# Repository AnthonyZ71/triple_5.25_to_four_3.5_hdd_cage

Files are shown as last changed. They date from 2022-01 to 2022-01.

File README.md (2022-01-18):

# Overview
OpenSCAD project to create a cage that fits in 3 5.25" drive bays and holds 4 3.5" hard drives using rails.

Optionally supports a fan shroud to provide additional airflow to the drives.

You need to print:

- 1 cage-cage.stl
- 8 cage-rail.stl
- [optional] 4 cage-fan_mounting_pin.stl
- [optional] 1 of the cage-fan_shroud stl files.

Note:  Monitor the print closely when printing the fan mounting pins.
They are very small and can detach from the bed fairly easily.
If you continue to have problems, perhaps print the pins on a raft.

Pictures are of the cage-fan_shroud_web.stl

Note that the cage has a cylinder channel cut out at the top and bottom on one side.
The channel is for routing the power cable of the fan to the back of the case.
It should be on the left side of the cage when it is inserted into the case.

- Code: [Github Repository](https://github.com/AnthonyZ71/triple_5.25_to_four_3.5_hdd_cage)
- STLs:
  - [Prusa Printers](https://www.prusaprinters.org/prints/120546-triple-525-bay-to-four-35-hard-drives-cage)

# Printing Notes
All parts except the rail are designed to be printed without supports.

I print all parts except the rail with typical settings for the material in which they are being printed.
- 5% infill is sufficient

For the rail:
- Plater -> 5% infill
- Plater -> Support on build plate only
- Print Settings -> Layers and perimeters -> Vertical shells -> Perimeters: 3
- Print Settings -> Layers and perimeters -> Quality -> Detect bridging perimeters: true
- Print Settings -> Support material -> Support material -> Overhang threshold -> 40

This should cause very little support to be generated by the pegs for the hard drives and the clip for latching into the cage.
The rest of the rail should not require support.

Note that the number of perimeters is increased from 2 to 3 to ensure that the pin of the rail is solid.
Check the result of slicing the rail, you only need enough perimeters to ensure a solid pin.

## Optional test print
The cage-test.stl doesn't need to be printed at all unless you want to test the tolerances with your printer before committing to a full print.
The components of the test print are all oriented as they would be printed individually, and allows validation of size / spacing of the print before committing the time to print all of the components.
The parts of the test print are:
- A single full channel and rail to allow validation that the rail slides easily and locks into the cage.
- A single fan shroud mounting pin to ensure that it will connect the front of the case to the fan shroud
- A slice of the cage to validate that it will slide into the bay openings for your computer
- A small portion of the fan shroud to ensure that the mounting pin will connect the shroud to the front of the cage.  (note that it is ok that the pin spins in the mounting holes.  Once all four pins lock the shroud to the full cage, it prevents movement.)

# My Equipment
- Prusa MK3
- PrusaSlicer-2.3.3

# References

Several other projects aided in the creation on this HDD cage.

## Modified Parametric Pin Connectors
This project makes use of [Modified Parametric Pin Connectors](https://www.thingiverse.com/thing:3218332) by [acwest](https://www.thingiverse.com/acwest/designs) on thingiverse.  After testing other fan mounting mechanisms, I liked using this pin and socket mechanism, primarily because even if I end up accidentally breaking a pin, printing out a new part is minutes, not hours.

## Customizable Fan Grill Covers
This project makes use of [Customizable Fan Grill Covers](https://www.thingiverse.com/thing:4837562) by [OutwardB](https://www.thingiverse.com/OutwardB) on thingiverse.

Several preset grills are provided using these settings:

all:
- Frame -> fan preset: 120mm
- Frame -> frame option: full
- Frame -> screw hole chamfer: bottom
- Frame -> min border size in millimeter: 5
- Pattern -> line size in millimeter: 1.6
- Advanced | Frame Setting -> rounded corners: no

crosshair
- Pattern -> grill pattern: crosshair
- Pattern -> line space in millimeter:  19.0

crosshex
- Pattern -> grill pattern: crosshex
- Pattern -> line space in millimeter:  8.0

grid:
- Pattern -> line space in millimeter:  8.0

teardrop:
- Pattern -> line space in millimeter:  8.0
- Pattern -> grill pattern rotation: 180

web:
- Pattern -> grill pattern: web
- Pattern -> line space in millimeter:  19.0

none:
- Frame -> screw hole chamfer: no

To create a custom grill, you can use any STL file that fits the grill pattern with the expectation that the front of the grill is what is facing down on the printer bed and that the center of the grill is at the origin [0, 0, 0] when the STL is loaded into OpenSCAD.
Use the settings describe above if using OutwardB's custom fan grill cover generator, and then make the desired changes, render, and export the STL as fan_cover_custom.stl
Then in OpenSCAD, select "fan_shroud" as the part, grill style of custom.
You will then see the customized fan shroud.
Render it and export the STL.

# Final Note
The current pictures are of an early iteration that used hinges for the fan shroud/cage instead of the pins.
The fan shroud was painted black to match the case.
All of the testing of the design worked fine until it was put into the case for actual use.
The fan shroud does not open far enough to access the drives.
With the fan shroud attached, the front of the case cannot be removed.
See the makes for pictures of the new design and I will update my photos when I reprint the case in the future.
The latest iteration is much better than the photos.

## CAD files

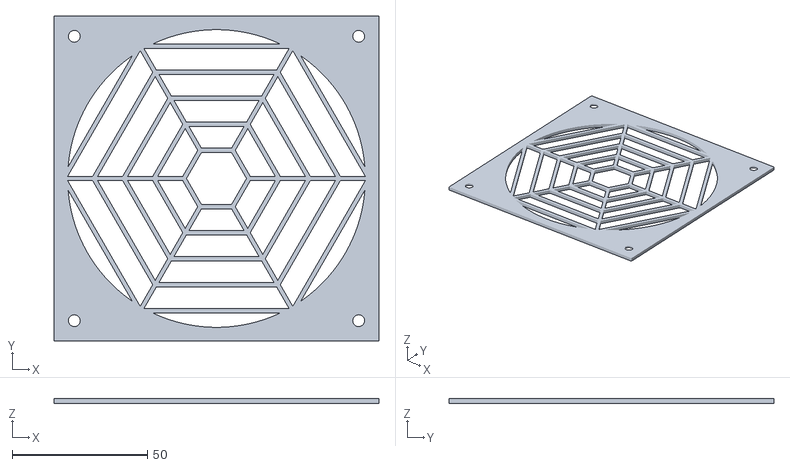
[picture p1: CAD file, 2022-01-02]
fan_cover_crosshex.stl
120.0 x 120.0 x 1.80

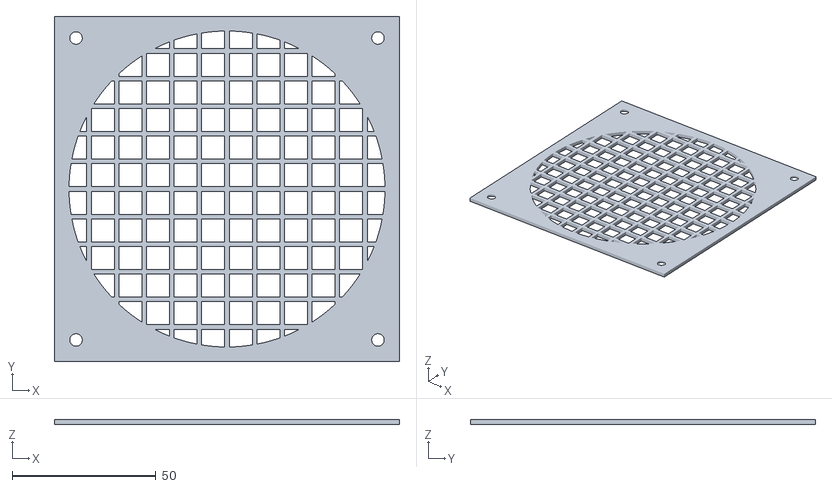
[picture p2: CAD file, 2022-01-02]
fan_cover_grid.stl
120.0 x 120.0 x 1.80

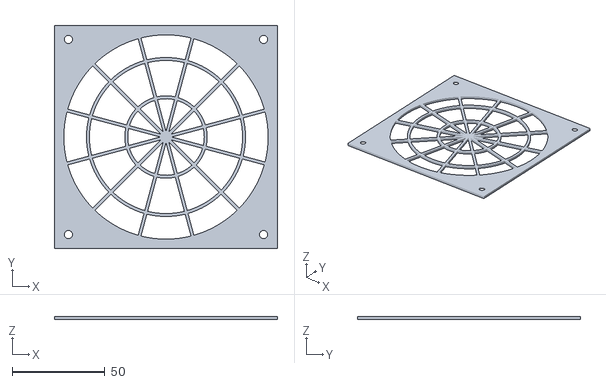
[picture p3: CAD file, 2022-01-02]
fan_cover_crosshair.stl
120.0 x 120.0 x 1.80

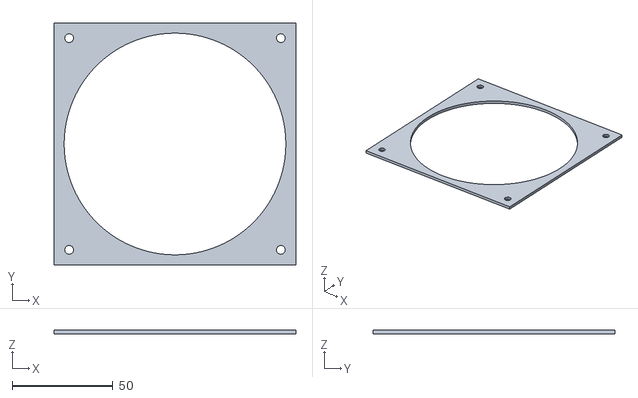
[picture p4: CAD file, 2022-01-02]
fan_cover_none.stl
120.0 x 120.0 x 1.80

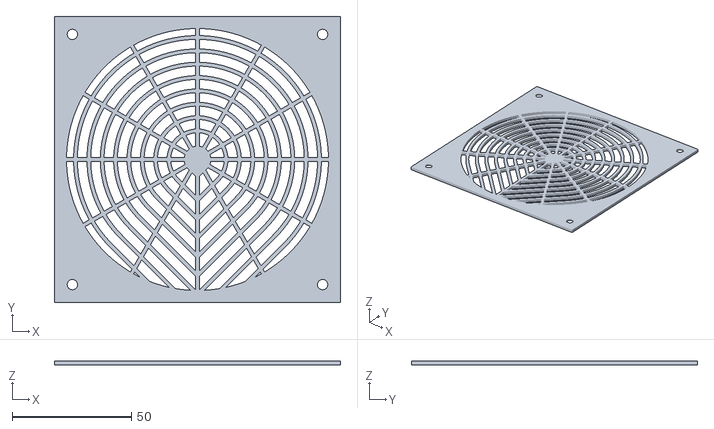
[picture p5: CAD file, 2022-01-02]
fan_cover_teardrop.stl
120.0 x 120.0 x 1.80

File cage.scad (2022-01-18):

use <snap-pins.scad>;

PART = "test"; // ["cage", "rail", "fan_shroud", "fan_mounting_pin", "test"]
// Select the grill style for the fan shroud.  Use custom and replace the fan_cover_custom.stl with your custom grill (see README.md for more details.)  Select none for an empty hole with an externally mounted grill cover.
grill_style = "fan_cover_web.stl"; // [fan_cover_crosshair.stl:crosshair,fan_cover_crosshex.stl:crosshex,fan_cover_grid.stl:grid,fan_cover_teardrop.stl:teardrop,fan_cover_web.stl:web,fan_cover_custom.stl:custom,fan_cover_none.stl:none]

include_fan_mount = true;

fan_grill_cover_height = 2;
shroud_h = 26;
shroud_inset = 11;

// How much tolerance to add to the prints.  This primarily impacts the rail channels, but also has some other impacts such as the pins on the rail that plug into the hard drive.
tolerance = .2;

bay_h = 41.3 + tolerance;
bay_w = 146.1 + tolerance;

drive_h = 29 + tolerance; // 41 + tolerance;
drive_w = 146 + tolerance;
drive_l = 165 + tolerance;

// See https://toshiba.semicon-storage.com/us/storage/support/faq/storage-holes.html
hdd_a1  =  26.10 + 0;
hdd_a2  = 147.00 + 0;
hdd_a3  = 101.60 + 0;
hdd_a4  =  95.25 + 0;
hdd_a5  =   3.18 + 0;
hdd_a6  =  44.45 + 0;
hdd_a7  =  41.28 + 0;
hdd_a8  =  28.50 + 0;
hdd_a9  = 101.60 + 0;
hdd_a10 =   6.35 + 0;
hdd_a13 =  76.20 + 0;

// See SFF-8551
cd_a1  =  41.53 + 0;
cd_a2  =  42.30 + 0;
cd_a3  = 148.00 + 0;
cd_a4  = 202.80 + 0;
cd_a5  = 146.05 + 0;
cd_a6  = 139.70 + 0;
cd_a7  =   3.18 + 0;
cd_a8  =  79.25 + 0;
cd_a9  =  47.40 + 0;
cd_a10 =  47.40 + 0;
cd_a11 =  79.25 + 0;
cd_a13 =  10.00 + 0;
cd_a14 =  21.84 + 0;
cd_a16 =   6.50 + 0;
cd_a17 =   5.00 + 0;

hdd_h = hdd_a1 + tolerance;
hdd_w = hdd_a3 + tolerance;
hdd_l = hdd_a2 + tolerance;

cage_h = 125.75 + 0;
cage_w = 145 + 0; // 146;
cage_l = hdd_a2 - hdd_a7 + 20; //cd_a10 + cd_a11 + 10;
total_rail_height = 8 + 0;

echo("old", cd_a10 + cd_a11 + 10);
echo("new", hdd_a2 - hdd_a7 + 20);

spacing_w = 4 + 0;

// pin connector settings.
snap_pin_pointed = 1;
snap_pin_fins = 1;
snap_pin_preload = 0.2;
snap_pin_clearance = 0.2;
snap_pin_printable = 1;
snap_pin_shadow_socket = 1;
snap_pin_spacing = 20;
snap_pin_cylinder_thickness = 2;

snap_pin_length = 6;
snap_pin_diameter = 3.2;
snap_pin_snap = 0.4;
snap_pin_snapDepth = 1.2;
snap_pin_thickness = 1.0;

$fn=$preview ? 18 : 120;

module vertical_hdd(l = hdd_l) {
    translate([hdd_h, 0, 0]) {
        rotate([0, -90, 0]) {
            cube([hdd_w, l, hdd_h]);
            translate([-total_rail_height + 0.01, 0, hdd_a10])
                rotate([0, 90, 0])
                    rail(false);
            translate([hdd_w + total_rail_height - 0.01, 0, hdd_a10])
                rotate([0, -90, 0])
                    rail(false);
        }
    }
}

module caged_hdds() {
    hdds_area = cage_w - spacing_w * 2;
    hdd_area = hdds_area / 4;
    for(i = [0 : 1 : 3 ]) {
        translate([i * hdd_area + spacing_w, -1, (cage_h - hdd_w) / 2])
            vertical_hdd(hdd_l + 2);
    }
}

module rail_spacing() {
    rail = 4;
    rail_s = 3;
    offset = sqrt(2 * rail * rail)/2 - rail_s / 2;

    translate([0, 1, -rail_s/2])
        rotate([0, 45, 0])
            cube([rail, cage_l*2, rail], center=true);
    translate([-offset, 1, 0])
        cube([rail_s, cage_l * 2, rail_s], center=true);
    translate([offset, 1, 0])
        cube([rail_s, cage_l * 2, rail_s], center=true);
    translate([0, 1, rail_s/2])
        rotate([0, 45, 0])
            cube([rail, cage_l*2, rail], center=true);
}

module fan_mounting_sockets() {
    center_w = cage_w/2;
    center_h = cage_h/2;
    corner_w = cage_w/2 - 4;
    corner_h = cage_h/2 - 8;
    snap_pin_radius = snap_pin_diameter / 2;
    cylinder_r = snap_pin_radius + snap_pin_snap + snap_pin_cylinder_thickness;
    cylnder_h = snap_pin_length + snap_pin_cylinder_thickness;
    for(w = [-1 : 2 : 1]) {
        x = center_w + corner_w * w;
        for (h = [-1 : 2 : 1]) {
            z = center_h + corner_h * h;
            translate([x, 0, z])
                rotate([-90, 0, 0])
                    showSocket(radius = snap_pin_radius,
                                length = snap_pin_length,
                                snapDepth = snap_pin_snapDepth,
                                snap = snap_pin_snap,
                                thickness = snap_pin_thickness,
                                pointed = snap_pin_pointed,
                                fixed = 0,
                                fins = false,
                                printable = false,
                                cylinderRadius = cylinder_r,
                                cylinderHeight = cylnder_h);
        }
    }
}

module cage() {
    cut = 7;
    difference() {
        // main area
        cube([cage_w, cage_l, cage_h]);
        // cut off harsh corners
        translate([0, cut, 0])
            rotate([0, 45, 0])
                cube([cut, cage_l*2, cut], center=true);
        translate([cage_w, cut, 0])
            rotate([0, 45, 0])
                cube([cut, cage_l*2, cut], center=true);
        translate([0, cut, cage_h])
            rotate([0, 45, 0])
                cube([cut, cage_l*2, cut], center=true);
        translate([cage_w, cut, cage_h])
            rotate([0, 45, 0])
                cube([cut, cage_l*2, cut], center=true);
        // cut out socket for mounting pin for fan
        if (include_fan_mount) {
            fan_mounting_sockets();
        }
        // cut out space for bay rails
        translate([cage_w, 0, cage_h*1/3 + 1.5])
            rail_spacing();
        translate([cage_w, 0, cage_h*2/3 + 1.5])
            rail_spacing();
        translate([0, 0, cage_h*1/3 + 1.5])
            rail_spacing();
        translate([0, 0, cage_h*2/3 + 1.5])
            rail_spacing();
        // cut out center stuff
        translate([cage_w/2, cage_l/2, cage_h/2])
            cube([hdd_h * 4 + spacing_w*7, cage_l * 2, hdd_w], center=true);
        // cut out the hdd vertical spacing
        translate([spacing_w, 0, 0])
            caged_hdds();
        // cut out 5.25" drive mounting holes.
        mounting_d = 3.0;
        for(drive = [0 : 1 : 2]) {
            drive_offset = drive * (cd_a2 + .5);
            for(set = [0 : 1 : 1]) {
                set_offset = cage_l - shroud_inset - (cd_a11 * set); // cd_a10 + cd_a11 * set;
                for(mount = [0 : 1 : 1]) {
                    mount_offset = mount ? cd_a13 : cd_a14;
                    translate([-10, set_offset, drive_offset + mount_offset]) {
                        rotate([0, 90, 0]) {
                            cylinder(20, d=mounting_d);
                        }
                    }
                    translate([-10 + cage_w, set_offset, drive_offset + mount_offset]) {
                        rotate([0, 90, 0]) {
                            cylinder(20, d=mounting_d);
                        }
                    }
                }
            }
        }
        // cut out routing for fan power cable.
        center_w = cage_w/2;
        center_h = cage_h/2;
        corner_w = (cage_w - spacing_w*4)/2 - 1;
        corner_h = hdd_w/2 - 1;
//        for(w = [-1 : 2 : 1]) {
// No space on the other side for cable routing.
        for(w = [-1 : 2 : -1]) {
            x = center_w + corner_w * w;
            for(h = [-1 : 2 : 1]) {
                z = center_h + corner_h * h;
                translate([x, cage_l/2, z])
                    rotate([90, 0, 0])
                        cylinder(cage_l + 2, r=3, center=true);
            }
        }
    }
}

module pin(pin_diameter, pin_length) {
    point = pin_diameter / 2;
    body = pin_length - point;

    rotate([0, 90, 0]) {
        translate([0, 0, -point/2]) {
            cylinder(h = body, d=pin_diameter, center=true);
            translate([0, 0, body/2])
                sphere(d = pin_diameter);
        }
    }
}

module clip(height, length, width) {
    angle = 16;

    translate([-width/2, 0, -height]) {
        difference() {
            rotate([angle, 0, 0])
                cube([width, length, height]);
            translate([-1, -2, height])
                cube([width * 2, length * 2, height + 2]);
            translate([-1, -length + 0.01, -0.01])
                cube([width * 2, length, height + 2]);
        }
    }
}

module handle(length, width, height, rail_height, positive=true) {
    t = tolerance;

    s1_l = length / 2;
    s2_angle = 40;
    // math to make the length of section 2 be half the
    // length of section 1.
    s2_l = (s1_l / 2) / cos(s2_angle);
    s2_x = s1_l;
    s3_l = (s1_l / 2);
    s3_z = (s1_l / 2) * tan(s2_angle);
    extension = s2_angle / 90 * height;

    clip_h = 1.5;
    clip_l = 6;
    clip_w = width / 3;
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

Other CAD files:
fan_cover_web.stl
fan_cover_custom.stl
snap-pins.scad

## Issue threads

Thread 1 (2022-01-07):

first use cage issues

AnthonyZ71, 2022-01-07:
- cage is maybe 1-2mm too wide...  Was hard to fit into the case.
- cage is maybe 1mm too high.  Height didn't seem to plays as much a roles a width, bu it was slightly too high.

AnthonyZ71, 2022-01-07:
cage width from 147 to 145.
cage height from 127 to 125.75.

Closed 2022-01-07.

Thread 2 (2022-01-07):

first use fan shroud issues

AnthonyZ71, 2022-01-07:
- fan mount can't open when the case front panel is on.  Can't take the front panel off when the fan shroud is mounted.  Need a different mounting mechanism to mount the fan.
- consider using the pin joints used for Choji cosplay armor - lots of pluses using this mechanism, the pins only take a few minutes to print if one breaks.
- consider moving cd-rom mounting holes forward as much as possible to shift the cage back into the case as far as possible and only make the cage long enough for the mounting holes + 5mm on each side.
- see if moving the case makes it possible to make the fan shroud stick out the same distance the bezel of a cd-rom is designed to stick out.  Keep in mind the cd-rom mounting rails...  They will probably cause problems for the fan, but the fan is wide enough that it might be able to accommodate the rails as well.
- See if the back of the hdds sit at the same location as a cd-rom would sit, and consider making that happen if it's not already at that point.

AnthonyZ71, 2022-01-07:
Switched to using the snap-pins.scad file from the Choji cosplay armor.

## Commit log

2022-01-02 Initial commit of project.
    [cage.scad, fan_cover_crosshair.stl, fan_cover_crosshex.stl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]
2022-01-04 Made the fan cutout slightly bigger.
    [cage.scad]
2022-01-05 Initial version of slicing, bed isn't heated though.
2022-01-05 - Cut out a bit more around the top/bottom of the hard drive, there was no gap on the right-most drive bay for the drive to slide in. - Changed the clip angle from 20 to 16 to make the lip smaller. -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
    [cage.scad]
2022-01-07 Fixed issue #1: cage width from 147 to 145. cage height from 127 to 125.75.
    Fix part of issue #2:
    replaced the hinges with the snap pins.
    [cage.scad, snap-pins.scad]
2022-01-18 Added comment on rail perimeters
2022-01-18 Updates with feedback from James on my print.
    [cage.scad]
2022-01-18 Updated notes about fan power channel
